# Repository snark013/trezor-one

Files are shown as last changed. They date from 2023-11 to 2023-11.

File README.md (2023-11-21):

# trezor-one

Trezor One cryptocurrency wallet.

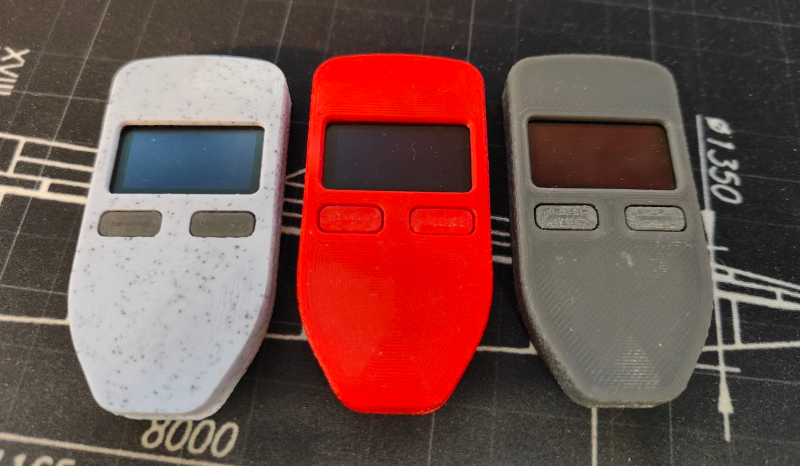
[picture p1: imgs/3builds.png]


Modified version of the original one from https://github.com/trezor/trezor-hardware

Modifications include -
- all R and C components of size 0603
- other buttons
- USB type-C connector

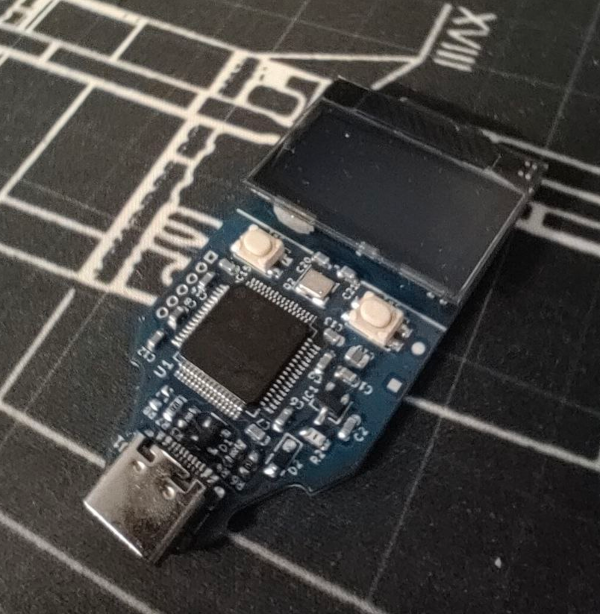
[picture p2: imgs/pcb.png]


As a result, the board is a bit longer and the case had to be modified as well.
The circuitry and firmware are original (only added two resistors to the circuit to allow the USB host to detect the connected device by the type-C connector).

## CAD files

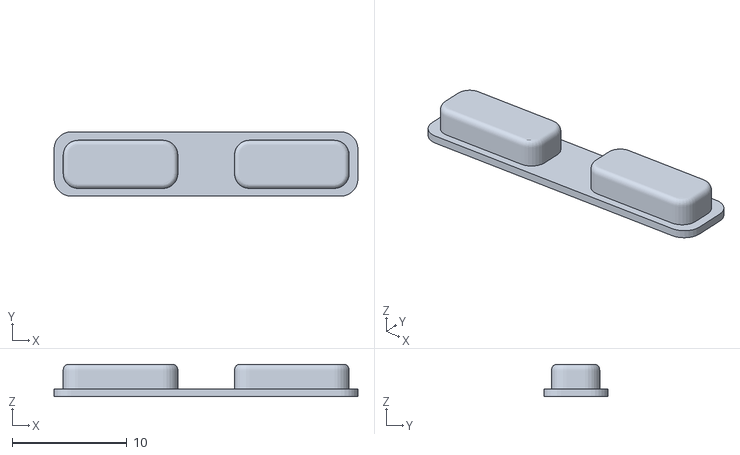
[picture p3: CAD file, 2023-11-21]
case/Buttons.stl
26.5 x 5.61 x 2.80

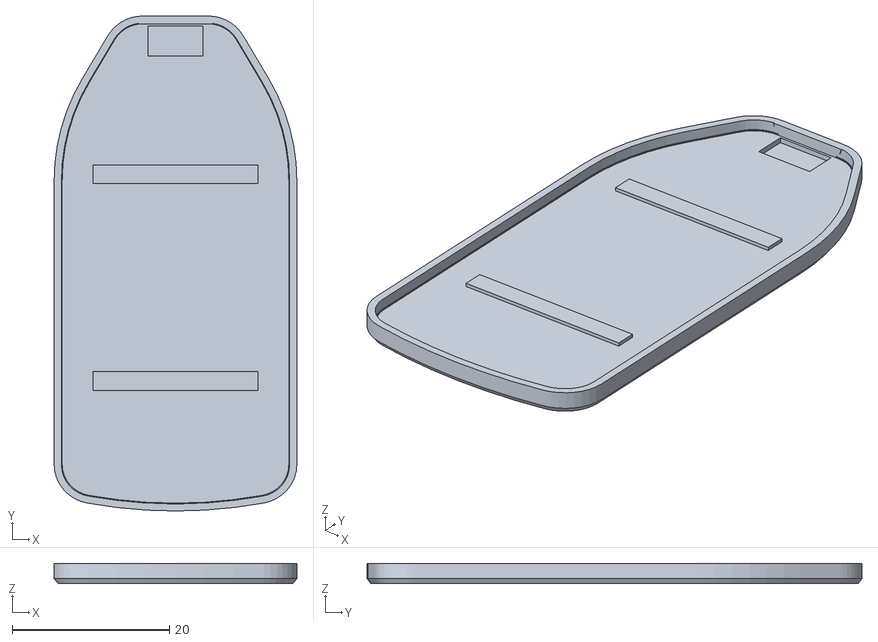
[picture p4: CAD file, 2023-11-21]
case/Case Bottom.stl
30.9 x 63.0 x 2.60

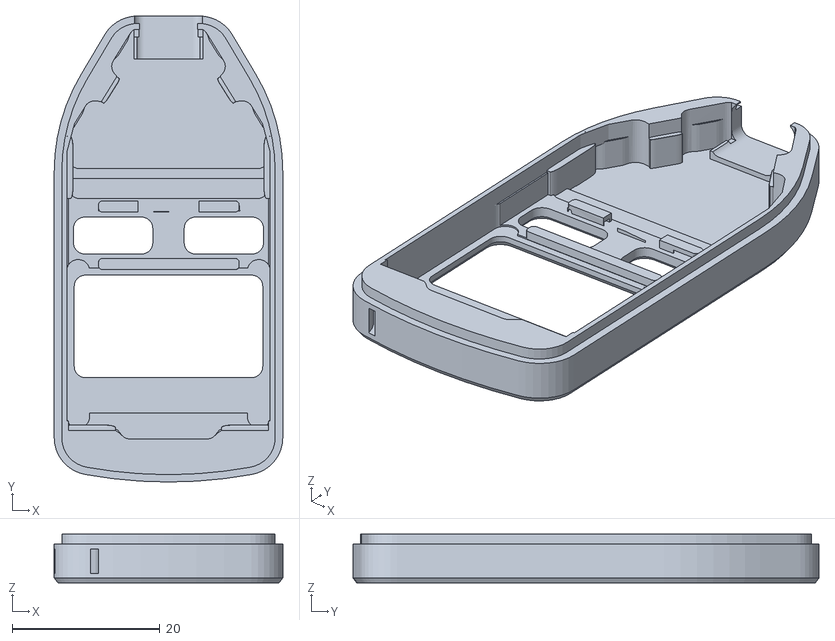
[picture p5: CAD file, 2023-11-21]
case/Case Top.stl
30.9 x 63.0 x 6.60

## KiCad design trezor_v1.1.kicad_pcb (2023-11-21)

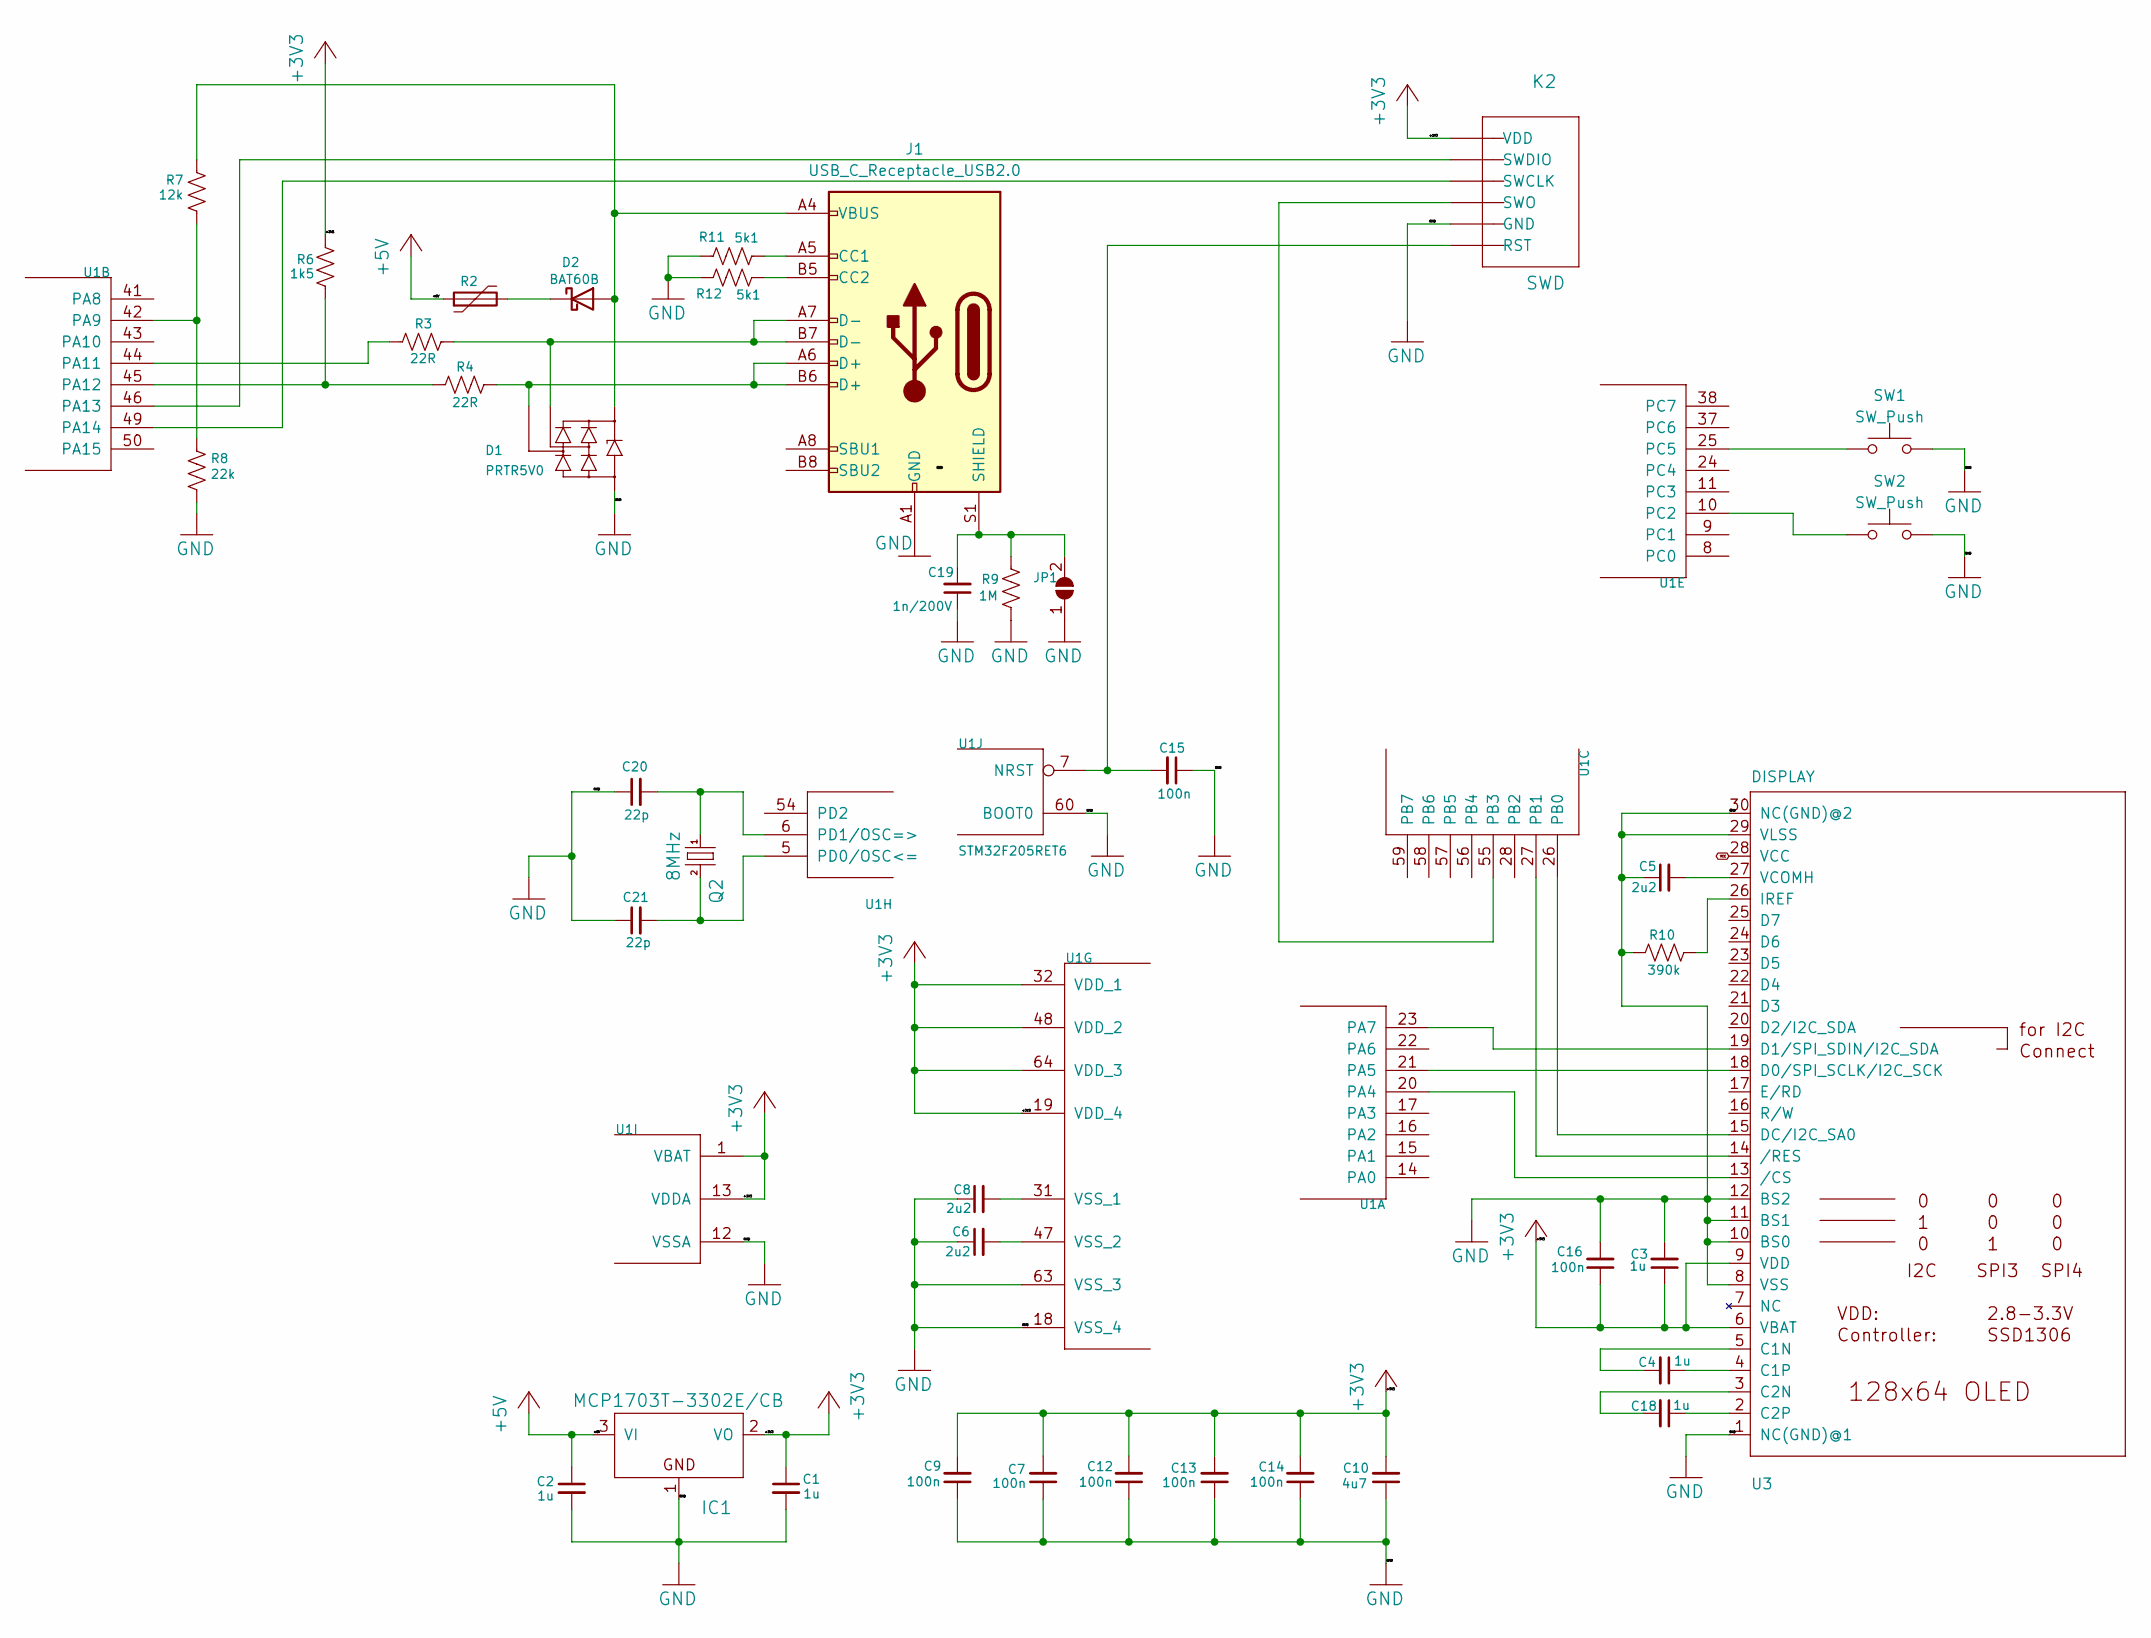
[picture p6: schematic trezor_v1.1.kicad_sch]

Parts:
C1, C2, C3, C4, C18: 1u; C_0603_1608Metric
C5, C6, C8: 2u2; C_0603_1608Metric
C7, C9, C12, C13, C14, C15, C16: 100n; C_0603_1608Metric
C10: 4u7; C_0603_1608Metric
C19: 1n/200V; C_0603_1608Metric
C20, C21: 22p; C_0603_1608Metric
D1: PRTR5V0; SOT-143_Handsoldering
D2: BAT60B; D_SOD-323_HandSoldering
IC1: MCP1703T-3302E/CB; TSOT-23
J1: USB_C_Receptacle_USB2.0; USB_C_Receptacle_HRO_TYPE-C-31-M-12
JP1: SolderJumper_2_Open; SolderJumper-2_P1.3mm_Open_RoundedPad1.0x1.5mm
K2: SWD
Q2: 8MHz; Crystal_SMD_3225-4Pin_3.2x2.5mm
R2: MF-FSMF020X-2; Fuse_0603_1608Metric_Pad1.05x0.95mm_HandSolder
R3, R4: 22R; R_0603_1608Metric
R6: 1k5; R_0603_1608Metric
R7: 12k; R_0603_1608Metric
R8: 22k; R_0603_1608Metric
R9: 1M; R_0603_1608Metric
R10: 390k; R_0603_1608Metric
R11, R12: 5k1; R_0603_1608Metric
SW1, SW2: SW_Push; SW_SPST_EVQP2
U1: STM32F205RET6; TQFP-64_10x10mm_P0.5mm
U3: DISPLAY; UG-2864HSWEG01_0.96IN_WRAPAROUND

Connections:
+3V3: C1.1, C3.1, C7.2, C9.2, C10.2, C12.2, C13.2, C14.2, C16.1, IC1.2 (VO), K2.6 (VDD), R6.1, U1.1 (VBAT), U1.13 (VDDA), U1.19 (VDD_4), U1.32 (VDD_1), U1.48 (VDD_2), U1.64 (VDD_3), U3.6 (VBAT), U3.9 (VDD)
+5V: C2.1, IC1.3 (VI), R2.1
GND: C1.2, C2.2, C3.2, C5.1, C6.1, C7.1, C8.1, C9.1, C10.1, C12.1, C13.1, C14.1, C15.1, C16.2, C19.1, C20.1, C21.1, D1.1 (GND), IC1.1 (GND), J1.A1 (GND), J1.A12 (GND), J1.B1 (GND), J1.B12 (GND), JP1.1 (A), K2.2 (GND), R8.1, R9.1, R10.1, R11.1, R12.1, SW1.2, SW2.2, U1.12 (VSSA), U1.18 (VSS_4), U1.60 (BOOT0), U1.63 (VSS_3), U3.1 (NC(GND)@1), U3.8 (VSS), U3.10 (BS0), U3.11 (BS1), U3.12 (BS2), U3.29 (VLSS), U3.30 (NC(GND)@2)
unnamed: D1.2 (I/O1), J1.A7 (D-), J1.B7 (D-), R3.2
unnamed: D1.3 (I/O2), J1.A6 (D+), J1.B6 (D+), R4.2
unnamed: D1.4 (VCC), D2.2 (A), J1.A4 (VBUS), J1.A9 (VBUS), J1.B4 (VBUS), J1.B9 (VBUS), R7.2
unnamed: D2.1 (K), R2.2
unnamed: J1.A5 (CC1), R12.2
unnamed: J1.B5 (CC2), R11.2
unnamed: C19.2, J1.S1 (SHIELD), JP1.2 (B), R9.2
unnamed: C15.2, K2.1 (RST), U1.7 (NRST)
unnamed: K2.4 (SWCLK), U1.49 (PA14)
unnamed: K2.5 (SWDIO), U1.46 (PA13)
unnamed: K2.3 (SWO), U1.55 (PB3)
unnamed: C21.2, Q2.3 (2), U1.5 (PD0/OSC<=)
unnamed: U1.20 (PA4), U3.13 (/CS)
unnamed: U1.21 (PA5), U3.18 (D0/SPI_SCLK/I2C_SCK)
unnamed: U1.23 (PA7), U3.19 (D1/SPI_SDIN/I2C_SDA)
unnamed: R7.1, R8.2, U1.42 (PA9)
unnamed: R3.1, U1.44 (PA11)
unnamed: R4.1, R6.2, U1.45 (PA12)
unnamed: U1.26 (PB0), U3.15 (DC/I2C_SA0)
unnamed: U1.27 (PB1), U3.14 (/RES)
unnamed: SW2.1, U1.10 (PC2)
unnamed: SW1.1, U1.25 (PC5)
unnamed: C8.2, U1.31 (VSS_1)
unnamed: C6.2, U1.47 (VSS_2)
unnamed: C20.2, Q2.1, U1.6 (PD1/OSC=>)
unnamed: C4.2, U3.5 (C1N)
unnamed: C4.1, U3.4 (C1P)
unnamed: C18.2, U3.3 (C2N)
unnamed: C18.1, U3.2 (C2P)
unnamed: R10.2, U3.26 (IREF)
unnamed: C5.2, U3.27 (VCOMH)
VCC: U3.28 (VCC)

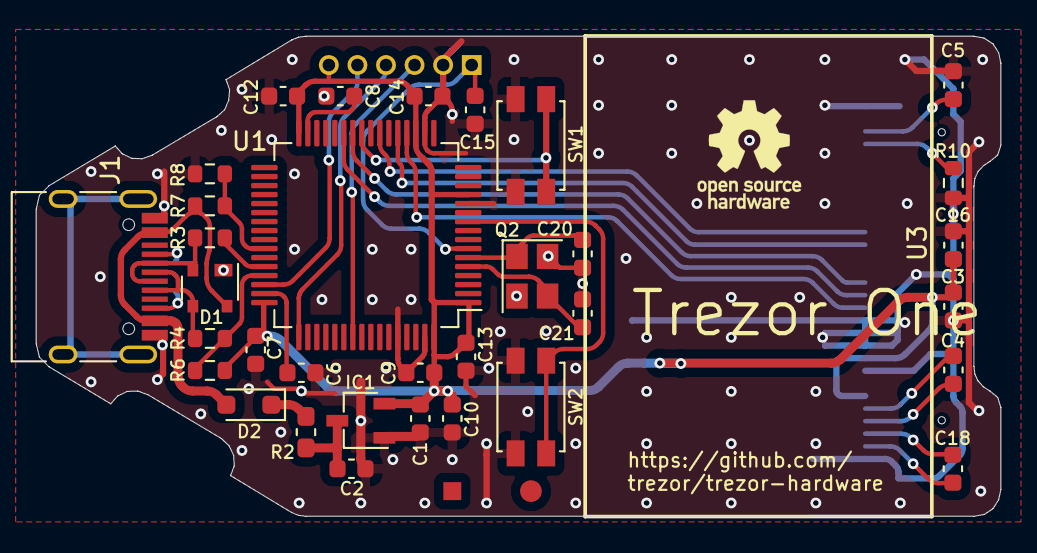
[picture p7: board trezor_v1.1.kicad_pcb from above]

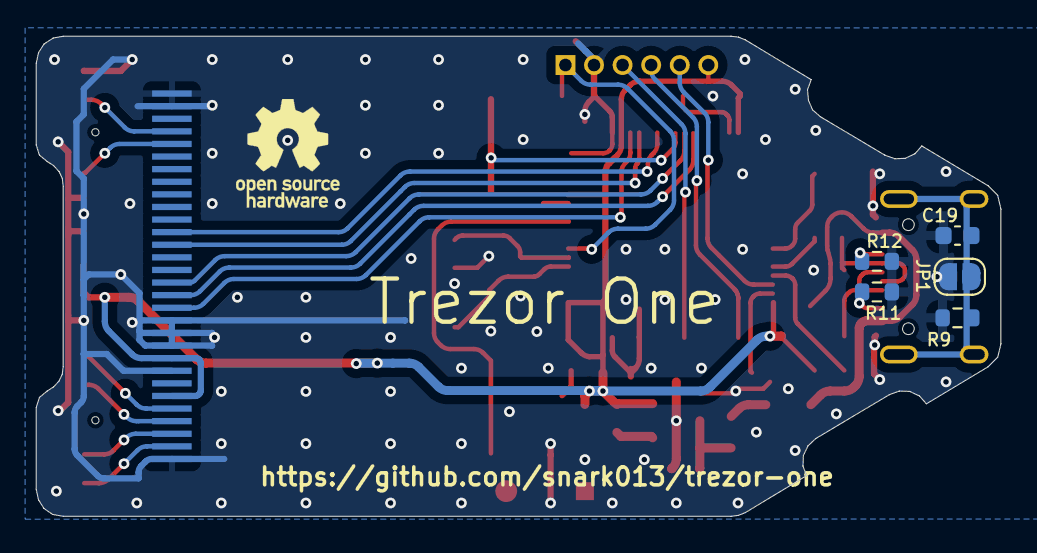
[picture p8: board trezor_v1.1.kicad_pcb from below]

Board: 2 copper layers, 53.6 x 26.7 mm, 42 parts (5 on the bottom side), 34 nets.

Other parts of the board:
U$3: BADMARK
U$4: CENTR
